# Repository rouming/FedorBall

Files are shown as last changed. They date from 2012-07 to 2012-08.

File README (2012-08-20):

NAME
    FedorBall -- is a toy-ball which detects current top position
    with accelerometer MMA7455 and turns on leds in special order
    using 4 led drivers TLC5940.

USED MATERIALS
    ATMEGA16
        http://www.atmel.com/Images/doc2466.pdf
        http://www.atmel.com/Images/doc8453.pdf
        http://www.tty1.net/blog/2008-04-29-avr-gcc-optimisations_en.html

    TLC5940
        http://code.google.com/p/tlc5940arduino/
        http://www.ti.com/lit/ds/symlink/tlc5940.pdf

    MMA7455
        http://arduino.cc/playground/Main/MMA7455
        http://www.freescale.com/files/sensors/doc/app_note/AN3468.pdf
        http://cache.freescale.com/files/sensors/doc/data_sheet/MMA7455L.pdf?fpsp=1

    TWI(I2C)
        http://easyelectronics.ru/avr-uchebnyj-kurs-ispolzovanie-avr-twi-dlya-raboty-s-shinoj-iic-i2c.html

    DODECAHEDRON INFO
        http://ru.wikipedia.org/wiki/Додекаэдр
        http://www.maths.surrey.ac.uk/hosted-sites/R.Knott/Fibonacci/phi3DGeom.html

    RAY-TRIANGLE INTERSECTION
        http://jgt.akpeters.com/papers/MollerTrumbore97/

    FIXED POINT
        http://gcc.gnu.org/wiki/FixedPointArithmetic
        http://x86asm.net/articles/fixed-point-arithmetic-and-tricks/

    OPENGL
        http://www.songho.ca/opengl/gl_vertexarray.html

AUTHOR
    Roman Pen

USERS
    son Fedor

ACKNOWLEDGEMENTS
COPYRIGHT & LICENSE
    Copyright 2012 Roman Pen

    This program is free software; you can redistribute it and/or modify it
    under the terms of either: the GNU General Public License as published
    by the Free Software Foundation

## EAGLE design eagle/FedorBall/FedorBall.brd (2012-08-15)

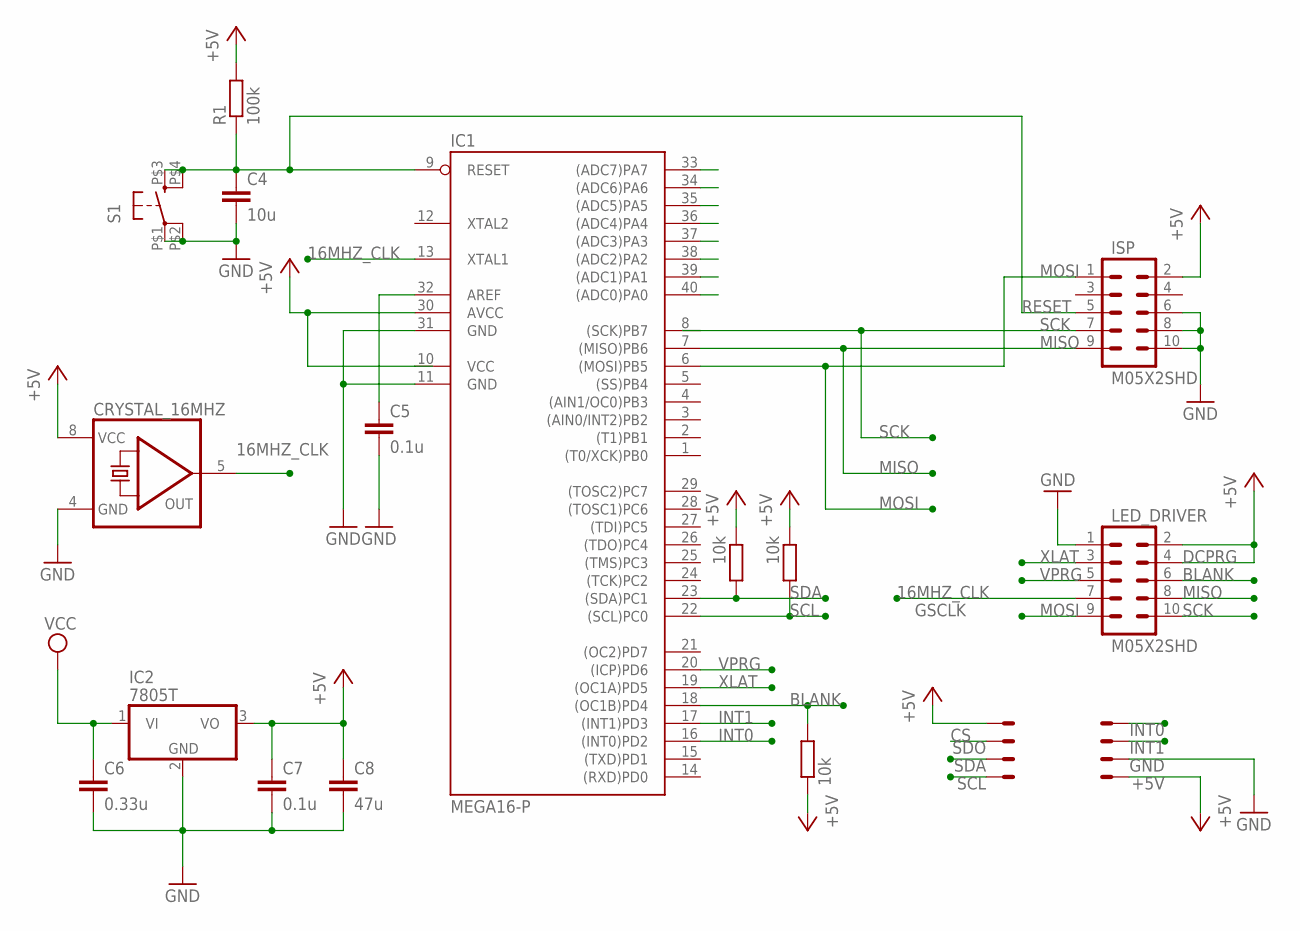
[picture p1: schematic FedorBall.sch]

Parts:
C4: 10u; C050-024X044
C5, C7: 0.1u; C050-024X044
C6: 0.33u; C050-024X044
C8: 47u; C050-024X044
CRYSTAL_16MHZ: QG5460; DIL08S
IC1: MEGA16-P; DIL40
IC2: 7805T; TO220H
ISP: M05X2SHD; 2X5-SHROUDED
LED_DRIVER: M05X2SHD; 2X5-SHROUDED
R1: 100k; 0207/10
R2, R5, R6: 10k; 0207/10
S1: TAC_SWITCHKSA_SEALED; KSA_SEALED_TAC_SWITCH
X1, X2: 22-23-2041

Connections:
16MHZ_CLK: CRYSTAL_16MHZ.5 (OUT), IC1.13 (XTAL1), LED_DRIVER.7
+5V: C7.1, C8.1, CRYSTAL_16MHZ.8 (VCC), IC1.10 (VCC), IC1.30 (AVCC), IC2.3 (VO), ISP.2, LED_DRIVER.2, LED_DRIVER.4, R1.2, R2.1, R5.1, R6.1, X1.1, X2.4
BLANK: IC1.18 ((OC1B)PD4), LED_DRIVER.6, R2.2
GND: C4.2, C5.2, C6.2, C7.2, C8.2, CRYSTAL_16MHZ.4 (GND), IC1.11 (GND), IC1.31 (GND), IC2.2 (GND), ISP.6, ISP.8, ISP.10, LED_DRIVER.1, S1.P$1 (1), S1.P$2 (2), X1.2
INT0: IC1.16 ((INT0)PD2), X1.4
INT1: IC1.17 ((INT1)PD3), X1.3
MISO: IC1.7 ((MISO)PB6), ISP.9, LED_DRIVER.8
MOSI: IC1.6 ((MOSI)PB5), ISP.1, LED_DRIVER.9
unnamed: C5.1, IC1.32 (AREF)
unnamed: C4.1, IC1.9 (RESET), ISP.5, R1.1, S1.P$3 (3), S1.P$4 (4)
SCK: IC1.8 ((SCK)PB7), ISP.7, LED_DRIVER.10
SCL: IC1.22 ((SCL)PC0), R6.2, X2.1
SDA: IC1.23 ((SDA)PC1), R5.2, X2.2
SDO: X2.3
VCC: C6.1, IC2.1 (VI)
VPRG: IC1.20 ((ICP)PD6), LED_DRIVER.5
XLAT: IC1.19 ((OC1A)PD5), LED_DRIVER.3

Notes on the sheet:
DCPRG
SCK
MISO
MOSI
RESET
GSCLK

Board: 2 copper layers, 17 parts (15 on the bottom side), 16 nets, no tracks yet.

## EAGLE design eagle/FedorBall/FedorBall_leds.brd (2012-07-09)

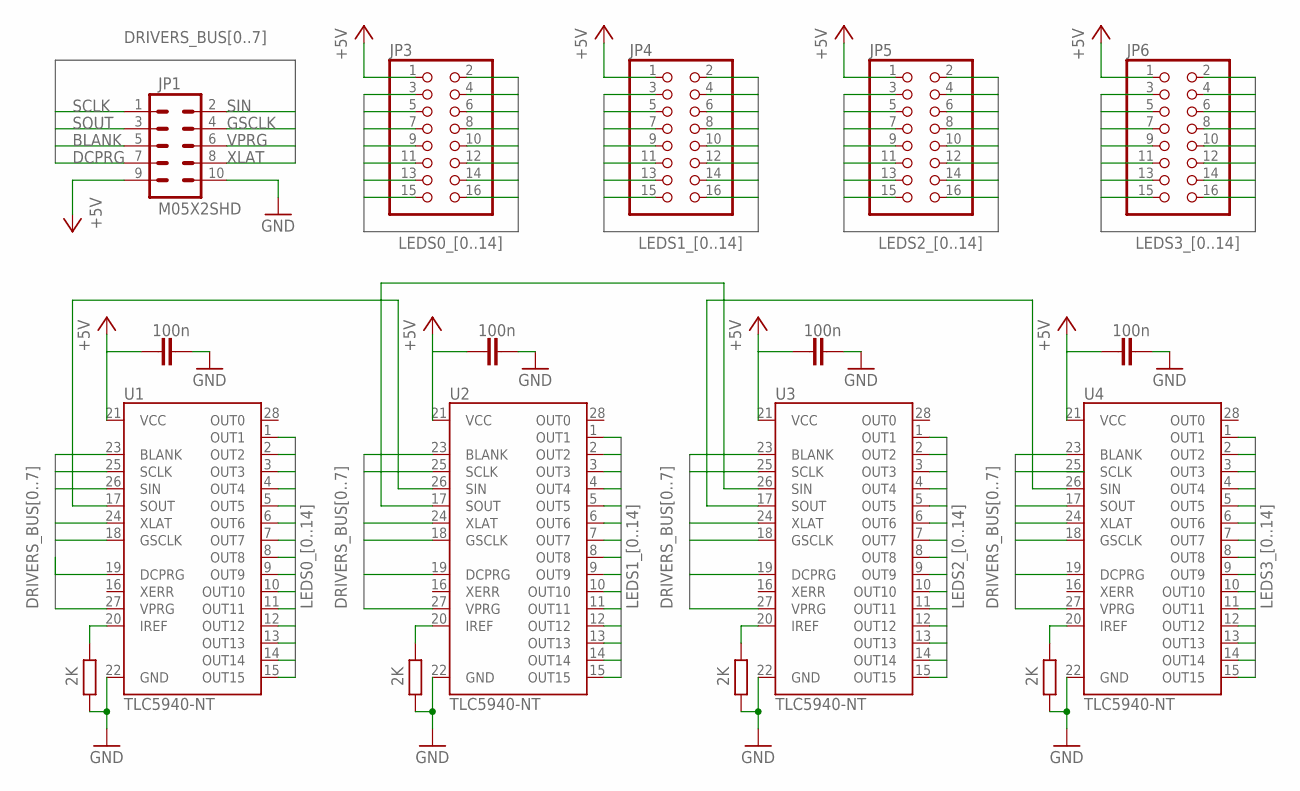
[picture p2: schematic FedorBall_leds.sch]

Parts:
C1, C2, C3, C4: 100n; C025-024X044
JP1: M05X2SHD; 2X5-SHROUDED
JP3, JP4, JP5, JP6: PINHD-2X8; 2X08
R1, R2, R3, R4: 2K; 0204/5
U1, U2, U3, U4: TLC5940-NT; DIL28-3

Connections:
+5V: C1.1, C2.1, C3.1, C4.1, JP1.9, JP3.1, JP4.1, JP5.1, JP6.1, U1.21 (VCC), U2.21 (VCC), U3.21 (VCC), U4.21 (VCC)
DRIVERS_BUS0: JP1.5, U1.23 (BLANK), U2.23 (BLANK), U3.23 (BLANK), U4.23 (BLANK)
DRIVERS_BUS1: JP1.1, U1.25 (SCLK), U2.25 (SCLK), U3.25 (SCLK)
DRIVERS_BUS2: JP1.2, U1.26 (SIN)
DRIVERS_BUS3: JP1.3, U4.17 (SOUT)
DRIVERS_BUS4: JP1.8, U1.24 (XLAT), U2.24 (XLAT), U3.24 (XLAT), U4.24 (XLAT)
DRIVERS_BUS5: JP1.4, U1.18 (GSCLK), U2.18 (GSCLK), U3.18 (GSCLK), U4.18 (GSCLK)
DRIVERS_BUS6: JP1.7, U1.19 (DCPRG), U2.19 (DCPRG), U3.19 (DCPRG), U4.19 (DCPRG)
DRIVERS_BUS7: JP1.6, U1.27 (VPRG), U2.27 (VPRG), U3.27 (VPRG), U4.27 (VPRG)
GND: C1.2, C2.2, C3.2, C4.2, JP1.10, R1.1, R2.1, R3.1, R4.1, U1.22 (GND), U2.22 (GND), U3.22 (GND), U4.22 (GND)
LEDS0_0: JP3.16, U1.1 (OUT1)
LEDS0_1: JP3.15, U1.2 (OUT2)
LEDS0_2: JP3.14, U1.3 (OUT3)
LEDS0_3: JP3.13, U1.4 (OUT4)
LEDS0_4: JP3.12, U1.5 (OUT5)
LEDS0_5: JP3.11, U1.6 (OUT6)
LEDS0_6: JP3.10, U1.7 (OUT7)
LEDS0_7: JP3.9, U1.8 (OUT8)
LEDS0_8: JP3.8, U1.9 (OUT9)
LEDS0_9: JP3.7, U1.10 (OUT10)
LEDS0_10: JP3.6, U1.11 (OUT11)
LEDS0_11: JP3.5, U1.12 (OUT12)
LEDS0_12: JP3.4, U1.13 (OUT13)
LEDS0_13: JP3.3, U1.14 (OUT14)
LEDS0_14: JP3.2, U1.15 (OUT15)
LEDS1_0: JP4.16, U2.1 (OUT1)
LEDS1_1: JP4.15, U2.2 (OUT2)
LEDS1_2: JP4.14, U2.3 (OUT3)
LEDS1_3: JP4.13, U2.4 (OUT4)
LEDS1_4: JP4.12, U2.5 (OUT5)
LEDS1_5: JP4.11, U2.6 (OUT6)
LEDS1_6: JP4.10, U2.7 (OUT7)
LEDS1_7: JP4.9, U2.8 (OUT8)
LEDS1_8: JP4.8, U2.9 (OUT9)
LEDS1_9: JP4.7, U2.10 (OUT10)
LEDS1_10: JP4.6, U2.11 (OUT11)
LEDS1_11: JP4.5, U2.12 (OUT12)
LEDS1_12: JP4.4, U2.13 (OUT13)
LEDS1_13: JP4.3, U2.14 (OUT14)
LEDS1_14: JP4.2, U2.15 (OUT15)
LEDS2_0: JP5.16, U3.1 (OUT1)
LEDS2_1: JP5.15, U3.2 (OUT2)
LEDS2_2: JP5.14, U3.3 (OUT3)
LEDS2_3: JP5.13, U3.4 (OUT4)
LEDS2_4: JP5.12, U3.5 (OUT5)
LEDS2_5: JP5.11, U3.6 (OUT6)
LEDS2_6: JP5.10, U3.7 (OUT7)
LEDS2_7: JP5.9, U3.8 (OUT8)
LEDS2_8: JP5.8, U3.9 (OUT9)
LEDS2_9: JP5.7, U3.10 (OUT10)
LEDS2_10: JP5.6, U3.11 (OUT11)
LEDS2_11: JP5.5, U3.12 (OUT12)
LEDS2_12: JP5.4, U3.13 (OUT13)
LEDS2_13: JP5.3, U3.14 (OUT14)
LEDS2_14: JP5.2, U3.15 (OUT15)
LEDS3_0: JP6.16, U4.1 (OUT1)
LEDS3_1: JP6.15, U4.2 (OUT2)
LEDS3_2: JP6.14, U4.3 (OUT3)
LEDS3_3: U4.4 (OUT4)
LEDS3_4: JP6.12, U4.5 (OUT5)
LEDS3_5: JP6.11, U4.6 (OUT6)
LEDS3_6: JP6.10, U4.7 (OUT7)
LEDS3_7: JP6.9, U4.8 (OUT8)
LEDS3_8: JP6.8, U4.9 (OUT9)
LEDS3_9: JP6.7, U4.10 (OUT10)
LEDS3_10: JP6.6, U4.11 (OUT11)
LEDS3_11: JP6.5, U4.12 (OUT12)
LEDS3_12: JP6.4, U4.13 (OUT13)
LEDS3_13: JP6.3, U4.14 (OUT14)
LEDS3_14: JP6.2, U4.15 (OUT15)
unnamed: U1.17 (SOUT), U2.26 (SIN)
unnamed: U2.17 (SOUT), U3.26 (SIN)
unnamed: U3.17 (SOUT), U4.26 (SIN)
unnamed: R2.2, U1.20 (IREF)
unnamed: R4.2, U2.20 (IREF)
unnamed: R3.2, U3.20 (IREF)
unnamed: R1.2, U4.20 (IREF)

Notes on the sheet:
XLAT
VPRG
GSCLK
SIN
DCPRG
BLANK
SOUT
SCLK

Board: 2 copper layers, 17 parts (16 on the bottom side), 76 nets, no tracks yet.

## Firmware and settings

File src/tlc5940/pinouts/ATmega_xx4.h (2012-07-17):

/*  Copyright (c) 2009 by Alex Leone <acleone ~AT~ gmail.com>

    This file is part of the Arduino TLC5940 Library.

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
    You should have received a copy of the GNU General Public License
    along with The Arduino TLC5940 Library.  If not, see
    <http://www.gnu.org/licenses/>. */

#ifndef TLC_ATMEGA_XX8_H
#define TLC_ATMEGA_XX8_H

/** \file
    SPI and timer pins for the ATmega164/324/644.  Don't edit these.  All
    changeable pins are defined in tlc_config.h */

/** VPRG (Sanguino digital pin 15) -> VPRG (TLC pin 27) */
#define DEFAULT_VPRG_PIN    PD7
#define DEFAULT_VPRG_PORT   PORTD
#define DEFAULT_VPRG_DDR    DDRD

/** XERR (Sanguino digital pin 6) -> XERR (TLC pin 16) */
#define DEFAULT_XERR_PIN    PB6
#define DEFAULT_XERR_PORT   PORTB
#define DEFAULT_XERR_DDR    DDRB
#define DEFAULT_XERR_PINS   PINB

/** SIN (Sanguino digital pin 5) -> SIN (TLC pin 26) */
#define DEFAULT_BB_SIN_PIN      PB5
#define DEFAULT_BB_SIN_PORT     PORTB
#define DEFAULT_BB_SIN_DDR      DDRB
/** SCLK (Sanguino digital pin 7) -> SCLK (TLC pin 25) */
#define DEFAULT_BB_SCLK_PIN     PB7
#define DEFAULT_BB_SCLK_PORT    PORTB
#define DEFAULT_BB_SCLK_DDR     DDRB

/** MOSI (Sanguino digital pin 5) -> SIN (TLC pin 26) */
#define TLC_MOSI_PIN     PB5
#define TLC_MOSI_PORT    PORTB
#define TLC_MOSI_DDR     DDRB

/** SCK (Sanguino digital pin 7) -> SCLK (TLC pin 25) */
#define TLC_SCK_PIN      PB7
#define TLC_SCK_PORT     PORTB
#define TLC_SCK_DDR      DDRB

/** SS will be set to output as to not interfere with SPI master operation.
    If you have changed the pin-outs and the library doesn't seem to work
    or works intermittently, make sure this pin is set correctly.  This pin
    will not be used by the library other than setting its direction to
    output. */
#define TLC_SS_PIN       PB4
#define TLC_SS_DDR       DDRB

/** OC1A (Sanguino digital pin 13) -> XLAT (TLC pin 24) */
#define XLAT_PIN     PD5
#define XLAT_PORT    PORTD
#define XLAT_DDR     DDRD

/** OC1B (Sanguino digital pin 12) -> BLANK (TLC pin 23) */
#define BLANK_PIN    PD4
#define BLANK_PORT   PORTD
#define BLANK_DDR    DDRD

/** OC2B (Sanguino digital pin 14) -> GSCLK (TLC pin 18) */
#define GSCLK_PIN    PD6
#define GSCLK_PORT   PORTD
#define GSCLK_DDR    DDRD

#endif

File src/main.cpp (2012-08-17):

/*
 * FedorBall is a toy-ball which detects current top position
 * with accelerometer MMA7455 and turns on leds in special order
 * using 4 led drivers TLC5940.
 */
#include <avr/io.h>
#include <avr/interrupt.h>
#include <avr/sleep.h>
#include <util/delay.h>
#include <string.h>

#include "tlc5940/Tlc5940.h"

#include "mma7455.h"
#include "uart.h"
#include "twi.h"
#include "logging.h"

//#define FACES_WALKING_TEST
#include "coords.h"

#include "std.h"
#include "raytri.h"

/* 2g, level mode */
#define MMA7455_2G_LEVEL_MODE (_BV(MMA7455_GLVL0) | \
							   _BV(MMA7455_MODE1))

/* 2g, pulse mode */
#define MMA7455_2G_PULSE_MODE (_BV(MMA7455_GLVL0) | \
							   _BV(MMA7455_MODE0) | \
							   _BV(MMA7455_MODE1))
/* 2g, measurement mode */
#define MMA7455_2G_MEASUREMENT_MODE (_BV(MMA7455_GLVL0) | \
									 _BV(MMA7455_MODE0))

/* Rate in Hz, value must be big enough to store the result
   of F_CPU/TIMER0_RATE in 8-bit timer register */
#define TIMER0_RATE 100000UL

/* Size must be 2^N */
#define UART_RX_BUFF_SZ (1<<2)
/* Size must be 2^N */
#define UART_TX_BUFF_SZ (1<<8)

#define ABS(m) ((m) > 0 ? (m) : -(m))

/* Extract RGB components */
#define R_RGB(rgb) (((rgb)>>16) & 0xff)
#define G_RGB(rgb) (((rgb)>>8) & 0xff)
#define B_RGB(rgb) ((rgb) & 0xff)

/* Circular shift of RBB, from B to R */
#define SHIFT_RGB(rgb) (((rgb)<<8 |(rgb)>>16) & 0xffffff)

/* Set RGB color for tlc */
#define TLC_SET_RGB(tlc, tlc_vert, rgb)					\
	do {												\
		tlc.set((tlc_vert)[0], R_RGB(rgb) << 4);		\
		tlc.set((tlc_vert)[1], G_RGB(rgb) << 4);		\
		tlc.set((tlc_vert)[2], B_RGB(rgb) << 4);		\
	} while (0)

static unsigned char s_uart_rx_buff[UART_RX_BUFF_SZ];
static unsigned char s_uart_tx_buff[UART_TX_BUFF_SZ];
static volatile uint32_t s_msecs;

/* Forward RX to TX */
static void uart_rx_to_tx(void* rx_cb_data)
{
	(void)rx_cb_data;

	void *rx_p, *tx_p;
	uint16_t rx_sz, tx_sz, sz;
	uart_rx_ptr(&rx_p, &rx_sz);
	uart_tx_ptr(&tx_p, &tx_sz);
	sz = (rx_sz > tx_sz ? tx_sz : rx_sz);
	if (sz == 0)
		return;
	memcpy(tx_p, rx_p, sz);
	uart_rx_advance(sz);
	uart_tx_advance(sz);
}

/* Init external INT1 interrupt to handle level
   detection from accelerometer. */
static void int1_init()
{
	/* enable rising edge on INT1 */
	MCUCR |= (1<<ISC10) | (1<<ISC11);

	/* enable INT1 */
	GICR |= (1<<INT1);
}

/* Level interrupt from MMA7455 which wakes up MCU from sleep */
ISR(INT1_vect)
{
}

/* set up Timer 0 for ball idle counting */
static void timer0_init()
{
	/* Set CTC mode (Clear Timer on Compare Match) (p.76) */
	TCCR0 |= (1 << WGM01);

	/* No prescaler (p.85) */
	TCCR0 |= (1 << CS00);

	/* Set the compare register (OCR0).
	   Do not forget about -1, because we count from 0 */
	OCR0 = F_CPU / TIMER0_RATE - 1;

	/* Enable Output Compare Match Interrupt when TCNT0 == OCR0 */
	TIMSK |= (1 << OCIE0);
}

/* TIMER0 Output Compare Match Interrupt service routine
   works on TIMER0_RATE */
ISR(TIMER0_COMP_vect)
{
	/* Global variable to count the number timer fires  */
	static uint16_t s_timer_fires = 0;
	/* Count msecs */
	if (++s_timer_fires == TIMER0_RATE / 1000UL) {
		s_timer_fires = 0;
		++s_msecs;
	}
}

/* put MMA to level mode, put MCU to sleep and wait
   for external interrupt from accelerometer */
static void goto_sleep()
{
	int err;
	uint8_t val;

	/* put mma to 2g, level detection, skip calibration */
	err = MMA7455_init(MMA7455_2G_LEVEL_MODE, false);
	if (err != 0) {
		LOG("Error: put to level mode failed, %u\n", err);
		return;
	}

	/* INT1 pin is level detection interrupt */
	val = _BV(MMA7455_INTREG0);
	err = MMA7455_write(MMA7455_CTL1, &val, 1);
	if (err != 0) {
		LOG("Error: write of CTL1 failed, %u\n", err);
		return;
	}
	/* 4g * 16 counts/g = 0x40 */
	val = 0x40;
	err = MMA7455_write(MMA7455_LDTH, &val, 1);
	if (err != 0) {
		LOG("Error: write of LDTH failed, %u\n", err);
		return;
	}

	/* INT2 pin to high (clear last interrupt) */
	val = 0x03;
	err = MMA7455_write(MMA7455_INTRST, &val, 1);
	if (err != 0) {
		LOG("Error: write of INTRST failed, %u\n", err);
		return;
	}
	/* INT2 pin to low (clear last interrupt) */
	val = 0;
	err = MMA7455_write(MMA7455_INTRST, &val, 1);
	if (err != 0) {
		LOG("Error: write of INTRST failed, %u\n", err);
		return;
	}

	uart_disable();

	set_sleep_mode(SLEEP_MODE_IDLE);
	cli();

	/* save previous timsk and stop all timers to avoid spurious wakeups*/
	uint8_t timsk = TIMSK;
	TIMSK = 0;

	sleep_enable();
	sei();
	sleep_cpu();
	sleep_disable();

	/* restore timers */
	TIMSK = timsk;

	/* enable uart */
	uart_enable();

	/* put mma to 2g, measurement detection, skip calibration */
	err = MMA7455_init(MMA7455_2G_MEASUREMENT_MODE, false);
	if (err != 0) {
		LOG("Error: put to measurement mode failed, %u\n", err);
	}
}

#ifdef FACES_WALKING_TEST
static void do_faces_walking_test()
{
	Tlc5940 tlc;
	tlc.init();

	while (1) {
		for (unsigned int face_i = 0;
			 face_i < ARRAY_SIZE(s_faces_walking_test); ++face_i) {
			uint8_t face = s_faces_walking_test[face_i];
			fp_t x = s_face_coords_middle_test[face * 3 + 0];
			fp_t y = s_face_coords_middle_test[face * 3 + 1];
			fp_t z = s_face_coords_middle_test[face * 3 + 2];

			fp_t orig[] = {FPZERO, FPZERO, FPZERO};
			fp_t dir[] = {x, y, z};

			// Walk through every face triangle
			for (unsigned int i = 0;
				 i < ARRAY_SIZE(s_vert_tri_faces);
				 i += 3) {
				fp_t vert0[] = {
					s_coords_vert[s_vert_tri_faces[i + 0] * 3 + 0],
					s_coords_vert[s_vert_tri_faces[i + 0] * 3 + 1],
					s_coords_vert[s_vert_tri_faces[i + 0] * 3 + 2]};
				fp_t vert1[] = {
					s_coords_vert[s_vert_tri_faces[i + 1] * 3 + 0],
					s_coords_vert[s_vert_tri_faces[i + 1] * 3 + 1],
					s_coords_vert[s_vert_tri_faces[i + 1] * 3 + 2]};
				fp_t vert2[] = {
					s_coords_vert[s_vert_tri_faces[i + 2] * 3 + 0],
					s_coords_vert[s_vert_tri_faces[i + 2] * 3 + 1],
					s_coords_vert[s_vert_tri_faces[i + 2] * 3 + 2]};

				//Count intersection with triangle
				fp_t t, u, v;
				if (fixed_intersect_triangle(orig, dir,
											 vert0, vert1, vert2,
											 &t, &u, &v) && t > 0) {
					uint8_t face_idx = i/9*9;
					// dim red
					uint32 rgb = 0x400000;

					tlc.clear();

					// Set color for every tlc led in pentagon face
					TLC_SET_RGB(tlc,
								&s_leds_vert[s_vert_tri_faces[face_idx + 0] * 3],
								rgb);
					TLC_SET_RGB(tlc,
								&s_leds_vert[s_vert_tri_faces[face_idx + 1] * 3],
								rgb);
					TLC_SET_RGB(tlc,
								&s_leds_vert[s_vert_tri_faces[face_idx + 2] * 3],
								rgb);
					TLC_SET_RGB(tlc,
								&s_leds_vert[s_vert_tri_faces[face_idx + 7] * 3],
								rgb);
					TLC_SET_RGB(tlc,
								&s_leds_vert[s_vert_tri_faces[face_idx + 8] * 3],
								rgb);

					// Commit
					tlc.update();

					LOG("face %u (must be %u), v1=%u, v2=%u, v3=%u\n\n",
						i/9, face,
						s_vert_tri_faces[i + 0],
						s_vert_tri_faces[i + 1],
						s_vert_tri_faces[i + 2]);

					break;
				}
			}

			_delay_ms(5000);
		}
	}
}
#endif /* FACES_WALKING_TEST */

static void ball_loop()
{
	int error;
	uint8_t c;

	// Initialize the MMA7455, and do calibration
	error = MMA7455_init(MMA7455_2G_MEASUREMENT_MODE, 1);
	LOG("Freescale MMA7455 accelerometer, inited=%s\n",
		(error == 0 ? "OK" : "ERR"));

	// Read the Status Register
	MMA7455_read(MMA7455_STATUS, &c, 1);

	LOG("STATUS : %x\n", c);

	// Read the "Who am I" value
	MMA7455_read(MMA7455_WHOAMI, &c, 1);

	LOG("WHOAMI: %x\n", c);

	// Read the optional temperature output value (I always read zero)
	MMA7455_read(MMA7455_TOUT, &c, 1);

	LOG("TOUT: %d\n", c);

	Tlc5940 tlc;
	tlc.init();

	int prev_inited = 0;
	int	prev_x = 0, prev_y = 0, prev_z = 0;
	uint32_t prev_face = 0;
	uint32_t face = 0;
	uint32_t msecs = 0;

	/* Dim color, thinking about power saving */
	uint32_t rgb = 0x400000;

	while (1) {
		int x,y,z, error;
		x = y = z = 0;
		error = MMA7455_xyz(&x, &y, &z); // get the accelerometer values.
		if (error != 0) {
			LOG("xyz err: %x\n", error);
			_delay_ms(100);
			continue;
		}

		if (prev_inited &&
			ABS(prev_x - x) < 5 &&
			ABS(prev_y - y) < 5 &&
			ABS(prev_z - z) < 5) {
			/* Goto sleep if ball was not touched for 30 secs */
			if (s_msecs - msecs > 30000) {
				/* Drop all leds before sleep */
				tlc.clear();
				tlc.update();
				/* Sleep now */
				goto_sleep();
				msecs = s_msecs;
				continue;
			}
		}
		else {
			msecs = s_msecs;

			prev_inited = 1;
			prev_x = x;
			prev_y = y;
			prev_z = z;
		}

		fp_t orig[] = {FPZERO, FPZERO, FPZERO};
		fp_t dir[] = {ITOFP(y), -ITOFP(z), ITOFP(x)};

		// Walk through every face triangle
		for (unsigned int i = 0;
			 error == 0 &&
			 i < ARRAY_SIZE(s_vert_tri_faces);
			 i += 3) {
			fp_t vert0[] = {
				s_coords_vert[s_vert_tri_faces[i + 0] * 3 + 0],
				s_coords_vert[s_vert_tri_faces[i + 0] * 3 + 1],
				s_coords_vert[s_vert_tri_faces[i + 0] * 3 + 2]};
			fp_t vert1[] = {
				s_coords_vert[s_vert_tri_faces[i + 1] * 3 + 0],
				s_coords_vert[s_vert_tri_faces[i + 1] * 3 + 1],
				s_coords_vert[s_vert_tri_faces[i + 1] * 3 + 2]};
			fp_t vert2[] = {
				s_coords_vert[s_vert_tri_faces[i + 2] * 3 + 0],
				s_coords_vert[s_vert_tri_faces[i + 2] * 3 + 1],
				s_coords_vert[s_vert_tri_faces[i + 2] * 3 + 2]};

			//Count intersection with triangle
			fp_t t, u, v;
			if (fixed_intersect_triangle(orig, dir,
										 vert0, vert1, vert2,
										 &t, &u, &v) && t < 0) {
				uint8_t face_idx;

				face = i/9;
				face_idx = face*9;

				/* Get next color component if face was changed */
				if (prev_face != face) {
					rgb = SHIFT_RGB(rgb);
					prev_face = face;
				}

				/* here we do not try to optimize and to skip colors
				   update if prev_face == face */

				tlc.clear();

				// Set color for every tlc led in pentagon face
				TLC_SET_RGB(tlc,
							&s_leds_vert[s_vert_tri_faces[face_idx + 0] * 3],
							rgb);
				TLC_SET_RGB(tlc,
							&s_leds_vert[s_vert_tri_faces[face_idx + 1] * 3],
							rgb);
				TLC_SET_RGB(tlc,
							&s_leds_vert[s_vert_tri_faces[face_idx + 2] * 3],
							rgb);
				TLC_SET_RGB(tlc,
							&s_leds_vert[s_vert_tri_faces[face_idx + 7] * 3],
							rgb);
				TLC_SET_RGB(tlc,
							&s_leds_vert[s_vert_tri_faces[face_idx + 8] * 3],
							rgb);

				// Commit
				tlc.update();

				break;
			}
		}

		// 50 Hz
		_delay_ms(20);
	}
}

int main()
{
	/* Init UART */
	uart_init(9600, s_uart_rx_buff, UART_RX_BUFF_SZ,
			  s_uart_tx_buff, UART_TX_BUFF_SZ, uart_rx_to_tx, NULL);

	/* Init TWI(I2C) */
	twi_init(TWI_FREQ);

	/* Init timer0 */
	timer0_init();

	/* Init external interrupt INT1 */
	int1_init();

	// enable iterrupts
	sei();

#ifdef FACES_WALKING_TEST
	do_faces_walking_test();
	return 0;
#endif

	ball_loop();

	return 0;
}

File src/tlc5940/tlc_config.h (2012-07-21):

/*  Copyright (c) 2009 by Alex Leone <acleone ~AT~ gmail.com>

    This file is part of the Arduino TLC5940 Library.

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
    You should have received a copy of the GNU General Public License
    along with The Arduino TLC5940 Library.  If not, see
    <http://www.gnu.org/licenses/>. */

#ifndef TLC_CONFIG_H
#define TLC_CONFIG_H

#include <stdint.h>

/** \file
    Configuration for the Arduino Tlc5940 library.  After making changes to
    this file, delete Tlc5940.o in this folder so the changes are applied.

    A summary of all the options:
    - Number of TLCs daisy-chained: NUM_TLCS (default 1)
    - Enable/Disable VPRG functionality: VPRG_ENABLED (default 0)
    - Enable/Disable XERR functionality: XERR_ENABLED (default 0)
    - Should the library use bit-banging (any pins) or hardware SPI (faster):
        DATA_TRANSFER_MODE (default TLC_SPI)
    - Which pins to use for bit-banging: SIN_PIN, SIN_PORT, SIN_DDR and
        SCLK_PIN, SCLK_PORT, SCLK_DDR
    - The PWM period: TLC_PWM_PERIOD (be sure to change TLC_GSCLK_PERIOD
        accordingly!)

    How to change the pin mapping:
    - Arduino digital pin 0-7  = PORTD, PD0-7
    - Arduino digital pin 8-13 = PORTB, PB0-5
    - Arduino analog pin  0-5  = PORTC, PC0-5 */

/** Bit-bang using any two i/o pins */
#define TLC_BITBANG        1
/** Use the much faster hardware SPI module */
#define TLC_SPI            2

/* ------------------------ START EDITING HERE ----------------------------- */

/** Number of TLCs daisy-chained.  To daisy-chain, attach the SOUT (TLC pin 17)
    of the first TLC to the SIN (TLC pin 26) of the next.  The rest of the pins
    are attached normally.
    \note Each TLC needs it's own IREF resistor */
#define NUM_TLCS    4

/** Determines how data should be transfered to the TLCs.  Bit-banging can use
    any two i/o pins, but the hardware SPI is faster.
    - Bit-Bang = TLC_BITBANG
    - Hardware SPI = TLC_SPI (default) */
#define DATA_TRANSFER_MODE    TLC_SPI

/* This include is down here because the files it includes needs the data
   transfer mode */
#include "pinouts/chip_includes.h"

/* Set DATA_TRANSFER_MODE to TLC_BITBANG and change the pins below if you need
   to use different pins for sin and sclk.  The defaults are defined in
   pinouts/ATmega_xx8.h for most Arduino's. */

#if DATA_TRANSFER_MODE == TLC_BITBANG
/** SIN (TLC pin 26) */
#define SIN_PIN        DEFAULT_BB_SIN_PIN
#define SIN_PORT       DEFAULT_BB_SIN_PORT
#define SIN_DDR        DEFAULT_BB_SIN_DDR
/** SCLK (TLC pin 25) */
#define SCLK_PIN       DEFAULT_BB_SCLK_PIN
#define SCLK_PORT      DEFAULT_BB_SCLK_PORT
#define SCLK_DDR       DEFAULT_BB_SCLK_DDR
#endif


/** If more than 16 TLCs are daisy-chained, the channel type has to be uint16_t.
    Default is uint8_t, which supports up to 16 TLCs. */
#define TLC_CHANNEL_TYPE    uint8_t

/** Determines how long each PWM period should be, in clocks.
    \f$\displaystyle f_{PWM} = \frac{f_{osc}}{2 * TLC\_PWM\_PERIOD} Hz \f$
    \f$\displaystyle TLC\_PWM\_PERIOD = \frac{f_{osc}}{2 * f_{PWM}} \f$
    This is related to TLC_GSCLK_PERIOD:
    \f$\displaystyle TLC\_PWM\_PERIOD =
       \frac{(TLC\_GSCLK\_PERIOD + 1) * 4096}{2} \f$
    \note The default of 8192 means the PWM frequency is 976.5625Hz */
//#define TLC_PWM_PERIOD    8192
// We use external 16MHz crystal
#define TLC_PWM_PERIOD    2048

/** Determines how long each period GSCLK is.
    This is related to TLC_PWM_PERIOD:
    \f$\displaystyle TLC\_GSCLK\_PERIOD =
       \frac{2 * TLC\_PWM\_PERIOD}{4096} - 1 \f$
    \note Default is 3 */
#define TLC_GSCLK_PERIOD    3

/** Enables/disables VPRG (TLC pin 27) functionality.  If you need to set dot
    correction data, this needs to be enabled.
    - 0 VPRG is not connected.  <em>TLC pin 27 must be grounded!</em> (default)
    - 1 VPRG is connected
    \note VPRG to GND inputs grayscale data, VPRG to Vcc inputs dot-correction
          data */
#define VPRG_ENABLED    1

/** If disabled we assume that GSCLK pin of TLC is connected to some
	external generator or other MC */
#define GSCLK_ENABLED 0

/** Enables/disables XERR (TLC pin 16) functionality to check for shorted/broken
    LEDs
    - 0 XERR is not connected (default)
    - 1 XERR is connected
    \note XERR is active low */
#define XERR_ENABLED    0

/*  You can change the VPRG and XERR pins freely.  The defaults are defined in
    the chip-specific pinouts:  see pinouts/ATmega_xx8.h for most Arduino's. */

#if     VPRG_ENABLED
/** VPRG (TLC pin 27) */
#define VPRG_PIN        DEFAULT_VPRG_PIN
#define VPRG_PORT       DEFAULT_VPRG_PORT
#define VPRG_DDR        DEFAULT_VPRG_DDR
#endif

#if     XERR_ENABLED
/** XERR (TLC pin 16) */
#define XERR_PIN        DEFAULT_XERR_PIN
#define XERR_PORT       DEFAULT_XERR_PORT
#define XERR_DDR        DEFAULT_XERR_DDR
#define XERR_PINS       DEFAULT_XERR_PINS
#endif

/* ------------------------- STOP EDITING HERE ----------------------------- */
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

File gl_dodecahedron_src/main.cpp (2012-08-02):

///////////////////////////////////////////////////////////////////////////////
// main.cpp
// ========
// testing vertex array (glDrawElements, glDrawArrays)
//
//	AUTHOR: Song Ho Ahn (song.ahn@gmail.com)
// CREATED: 2005-10-04
// UPDATED: 2012-04-11
///////////////////////////////////////////////////////////////////////////////

#include <GL/glut.h>
#include <GL/glext.h>

// glm::vec3, glm::vec4, glm::ivec4, glm::mat4
#include <glm/glm.hpp>
// glm::translate, glm::rotate, glm::scale, glm::perspective
#include <glm/gtc/matrix_transform.hpp>
// glm::value_ptr
#include <glm/gtc/type_ptr.hpp>

#include <iostream>
#include <sstream>
#include <iomanip>
#include <set>
#include <list>

#include <math.h>
#include <stdio.h>
#include <assert.h>

#include "raytri.h"

using std::stringstream;
using std::cout;
using std::endl;
using std::ends;


// GLUT CALLBACK functions
void displayCB();
void reshapeCB(int w, int h);
void timerCB(int millisec);
void keyboardCB(unsigned char key, int x, int y);
void mouseCB(int button, int stat, int x, int y);
void mouseMotionCB(int x, int y);

void initGL();
int	 initGLUT(int argc, char **argv);
bool initSharedMem();
void clearSharedMem();
void initLights();
void setCamera(float posX, float posY, float posZ, float targetX, float targetY, float targetZ);
void drawString(const char *str, int x, int y, float color[4], void *font);
void drawString3D(const char *str, float pos[3], float color[4], void *font);
void toOrtho();
void toPerspective();
void drawDodecahedron();


// constants
const int	SCREEN_WIDTH	= 400;
const int	SCREEN_HEIGHT	= 300;
const float CAMERA_DISTANCE = 4.0f;
const int	TEXT_WIDTH		= 8;
const int	TEXT_HEIGHT		= 13;


// global variables
static void *font = GLUT_BITMAP_8_BY_13;
static int screenWidth;
static int screenHeight;
static bool mouseLeftDown;
static bool mouseRightDown;
static bool mouseMiddleDown;
static float mouseX, mouseY;
static float cameraAngleX;
static float cameraAngleY;
static float cameraDistance;
static int drawMode = 0;
static int maxVertices;
static int maxIndices;

#define pi 3.14159265358

struct point
{
	GLfloat x;
	GLfloat y;
	GLfloat z;
};

bool operator<(const point& p1, const point& p2)
{
	const GLfloat epsilon = 1e-8;

	if (p1.x < p2.x - epsilon) return true;
	if (p1.x > p2.x + epsilon) return false;

	if (p1.y < p2.y - epsilon) return true;
	if (p1.y > p2.y + epsilon) return false;

	if (p1.z < p2.z - epsilon) return true;

  return false;

	/*
	GLfloat sz1 = sqrt(p1.x*p1.x + p1.y*p1.y + p1.z*p1.z);
	GLfloat sz2 = sqrt(p2.x*p2.x + p2.y*p2.y + p2.z*p2.z);
	return sz1 < sz2;
	*/
	return p1.x < p2.x || p1.y < p2.y || p1.z < p2.z;
}

bool operator==(const point& p1, const point& p2)
{
	return p1.x == p2.x && p1.y == p2.y && p1.z == p2.z;
}

struct vector
{
	GLfloat x;
	GLfloat y;
	GLfloat z;
};

struct triangle
{
	point p0;
	point p1;
	point p2;
};

void create_triangle(GLfloat *vertices, unsigned int idx,
							triangle& tr)
{
	tr.p0.x = vertices[idx + 0];
	tr.p0.y = vertices[idx + 1];
	tr.p0.z = vertices[idx + 2];

	tr.p1.x = vertices[idx + 3];
	tr.p1.y = vertices[idx + 4];
	tr.p1.z = vertices[idx + 5];

	tr.p2.x = vertices[idx + 6];
	tr.p2.y = vertices[idx + 7];
	tr.p2.z = vertices[idx + 8];
};

void create_triangle(GLfloat *vertices, GLbyte *faces,
					 unsigned int idx, triangle& tr)
{
	tr.p0.x = vertices[faces[idx + 0] * 3 + 0];
	tr.p0.y = vertices[faces[idx + 0] * 3 + 1];
	tr.p0.z = vertices[faces[idx + 0] * 3 + 2];

	tr.p1.x = vertices[faces[idx + 1] * 3 + 0];
	tr.p1.y = vertices[faces[idx + 1] * 3 + 1];
	tr.p1.z = vertices[faces[idx + 1] * 3 + 2];

	tr.p2.x = vertices[faces[idx + 2] * 3 + 0];
	tr.p2.y = vertices[faces[idx + 2] * 3 + 1];
	tr.p2.z = vertices[faces[idx + 2] * 3 + 2];
};


static void vector_cross(const vector& a, const vector& b, vector& r)
{
	r.x = a.y * b.z - a.z * b.y;
	r.y = a.z * b.x - a.x * b.z;
	r.z = a.x * b.y - a.y * b.x;
}

static void vector_normalize(vector& v)
{
#define SMALL_VECTOR (1e-4)
	GLfloat size = sqrt(v.x*v.x + v.y*v.y + v.z*v.z);
	if (size < SMALL_VECTOR) {
		printf("Vector is too small!\n");
		exit(-1);
	}

	v.x /= size;
	v.y /= size;
	v.z /= size;
}

static void normal(const triangle& tr, vector& n)
{
	vector v1 = {tr.p1.x - tr.p0.x, tr.p1.y - tr.p0.y, tr.p1.z - tr.p0.z};
	vector v2 = {tr.p2.x - tr.p0.x, tr.p2.y - tr.p0.y, tr.p2.z - tr.p0.z};
	vector_cross(v1, v2, n);
	vector_normalize(n);
}

// (1.0 + sqrt(5.0)) / 2.0;
static float phi = 1.61803;
static float phi_1 = 1-phi;
static GLfloat dod_orig_vert[] =
{
	0, phi_1, phi,
	0, phi_1, -phi,
	0, -phi_1, phi,
	0, -phi_1, -phi,
	phi, 0, phi_1,
	phi, 0, -phi_1,
	-phi, 0, phi_1,
	-phi, 0, -phi_1,
	phi_1, phi, 0,
	phi_1, -phi, 0,
	-phi_1, phi, 0,
	-phi_1, -phi, 0,
	1, 1, 1,
	1, 1, -1,
	1, -1, 1,
	1, -1, -1,
	-1, 1, 1,
	-1, 1, -1,
	-1, -1, 1,
	-1, -1, -1

};

static GLbyte dod_orig_faces[] =
{
	12, 2, 0,	12, 0, 14,	12, 14, 5,
	10, 8, 16,	10, 16, 2,	10, 2, 12,
	17, 6, 7,	17, 7, 16,	17, 16, 8,
	16, 7, 18,	16, 18, 0,	16, 0, 2,
	0,	18, 9,	0,	9, 11,	0, 11, 14,
	5, 14, 11,	5, 11, 15,	5, 15, 4,
	13, 4, 15,	13, 15, 1,	13, 1, 3,
	17, 3, 1,	17, 1, 19,	17, 19, 6,

	10, 12, 5,	10, 5, 4,	10, 4, 13,
	3, 17, 8,	3, 8 ,10,	3, 10, 13,
	11, 9, 19,	11, 19, 1,	11, 1, 15,
	9, 18, 7,	9, 7, 6,	9, 6, 19,
};

//faces * verteces_per_face * cords_in_3d
static GLfloat dod_vert[12*5*3];
//faces * verteces_per_face * cords_in_3d
static GLfloat dod_normals[12*5*3];
//faces * triangles_per_face * points_per_triangle
static GLbyte dod_faces[12*3*3];
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

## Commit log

2012-06-18 eagle scheme scratch
    [FedorBall.brd, FedorBall.sch]
2012-06-19 update main scheme and board
    [FedorBall.brd, FedorBall.sch]
2012-06-19 add scheme and board for leds managing
    [FedorBall_leds.brd, FedorBall_leds.sch]
2012-06-19 continue implementing leds driver scheme
    [FedorBall_leds.brd, FedorBall_leds.sch]
2012-06-28 decrease camera distance
2012-07-02 calcalate x,y,z of camera eye and set this coords to crossing ray
2012-07-02 ray-triangle intersection on fixed point
    [main.cpp]
2012-07-05 schematic tweaks
    [FedorBall.brd, FedorBall.sch]
2012-07-06 update scheme
    [FedorBall.brd, FedorBall.sch, FedorBall_leds.brd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]
2012-07-09 update leds board scheme
    [FedorBall_leds.brd, FedorBall_leds.sch]
2012-07-12 update schematic for main board
    [FedorBall.brd, FedorBall.sch]
2012-07-17 we use 4 tlc chained for fedor ball not 1
2012-07-18 enable global interrupts
2012-07-19 start UART implementation
2012-07-19 add ring buffer to uart
2012-07-19 uart interrupt-driven implementation using ring buffer
2012-07-19 add logging file with LOG macros which uses uart_printf call
2012-07-19 init uart and use first log msg
2012-07-20 add tty.c to test USB-UART bridge and uart implementation
2012-07-20 use external generator instead of glitchy internal oscillator
    uart does not want to work on internal oscillator!!!
2012-07-20 init uart in more standard mode: 8bit, 1stop bit, no parity
2012-07-21 connect GSCLK pin of TLC to external 16Mhz crystal
2012-07-21 reset TX ring buffer if nothing to send any more
    reset means 'start from the beginning'
    so, to avoid buffer split on two parts: bottom and half
    at the end just reset indices
    [uart.c]
2012-07-22 start implementing interrupt-driven i2c (twi in avr terms)
2012-07-23 twi interrupt driven implementation
2012-07-24 remove useless atomic block from uart_init function. simply disable uart at start of the call.
2012-07-24 fix uart_printf: check overflow
    [uart.c]
2012-07-24 define uart buffers in some other place, not in uart.c itself
2012-07-24 port arduino mma7455 driver to atmega16
2012-07-25 update schematic and board according to last hardware experiments
    [FedorBall.brd, FedorBall.sch]
2012-07-29 describe leds on ball with their indices
2012-07-31 normalize dodecahedron coords and rotate it on 31.717 angle around X axis to have bottom face on X plane
2012-08-01 code size optimization, part 1
    rename int32->int16
    ring_buffer.h
    uart.h
    uart.c
    main.cpp
    Program: 13202 bytes (80.6% full)
    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
2012-08-02 compiller does not calculate correctly fp_to_f, so calculate it in gl_dodecahedron app and copy output to coords.h
    [main.cpp]
2012-08-02 map accel coords system to gl coords system, yzx -> xyz
    also invert accel z coord
    [main.cpp]
2012-08-09 made mistake while real assembling of fedor ball -> advance indices for #2 tlc on 1
2012-08-13 top leds must be anticlockwise, not clockwise. do swap
2012-08-13 comments tweaks: change scheme of leds on dodecahedron
2012-08-13 fix faces walking test
    [main.cpp]
2012-08-15 tweaks: increase ball freq from 10 to 50 hz, make red color to be dim
2012-08-15 minor scheme changes
    [FedorBall.brd, FedorBall.sch]
2012-08-15 put mcu to sleep if accel does not report x,y,z changes > threshold for 30 seconds
    mcu will be waken up by external interrupt from accel, which will be put
    in pulse mode before mcu sleep
2012-08-17 do not stop other timers while setting/unsetting XLAT timer
2012-08-17 enable only int1 interrupt and implement empty int1 handler
2012-08-17 fix mma7455 init procedure: forgotten mode set
    [mma7455.c, mma7455.h]
2012-08-17 enable uart disable/enable calls
2012-08-17 fix goto sleep routine: switch accel to level detection mode, stop timers and uart before sleep
    [main.cpp]
2012-08-20 add used materials links to readme file

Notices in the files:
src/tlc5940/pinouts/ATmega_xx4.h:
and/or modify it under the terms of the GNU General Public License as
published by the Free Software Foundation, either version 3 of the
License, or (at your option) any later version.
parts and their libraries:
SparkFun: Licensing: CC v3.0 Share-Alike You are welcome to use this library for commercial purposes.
